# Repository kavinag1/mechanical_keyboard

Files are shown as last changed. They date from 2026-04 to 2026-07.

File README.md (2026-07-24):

# Building My Own 60% Mechanical Keyboard with a Raspberry Pi Pico

I have been wanting a mechanical keyboard. So instead of buying one why not make one. This was not really a easy journey but I am proud of what all I have learnt

---

## The Journey

### Step 0: Deciding the keyboard (1hr)
Over the past few days, I researched different types of keyboards to decide what I want to build. I compared layouts like 40%, 60%, 65%, and TKL, and chose a 60% layout because it offers a good balance between size and functionality while still being manageable to design. I also looked at existing open-source designs like the CO60 to understand how keyboard PCBs are structured and to confirm standard design practices.

I also researched switches, connectivity, and firmware. I selected EPOMAKER Creamy Jade switches because they are MX-style and compatible with standard footprints. I decided to make the keyboard wired instead of wireless to reduce complexity and allow me to use QMK firmware more easily.

The final specifications of my keyboard include a 60% layout, MX-style 5-pin switches, a row-column matrix with 1N4148 diodes, USB-C connectivity, and an STM32-based microcontroller. I will also include a rotary encoder for extra functionality and simple per-key backlighting. This research helped me clearly define my design before moving on to the PCB stage.

### Step 1: Learning What a Keyboard Matrix Is (1.5hr)

so before I could build this keyboard I needed to pratice what keyboard matrix is and understand how it works. So I followed a tutorial to make a simple and easy 3 by 3 keybaord matrix like the one you can see in the image. Keyboard matrix allows you to add more keys and use less number of pins like here I used 9 keys but only used 6 pins. This would be useful in the future when making the actual keyboard cause raspberry pico has only so many number of pins.

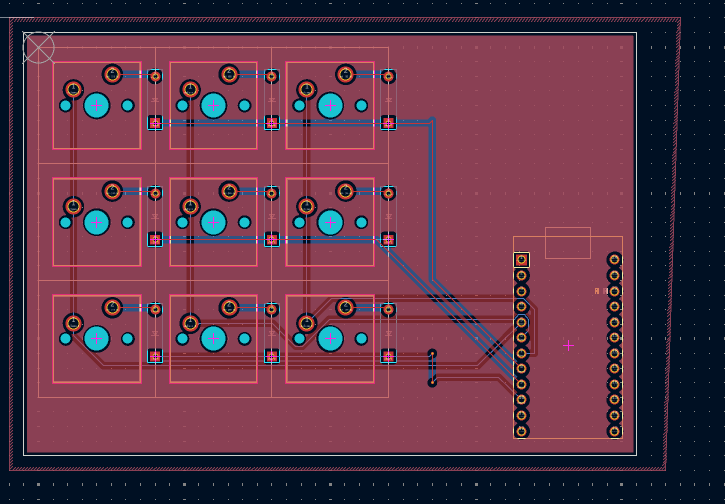
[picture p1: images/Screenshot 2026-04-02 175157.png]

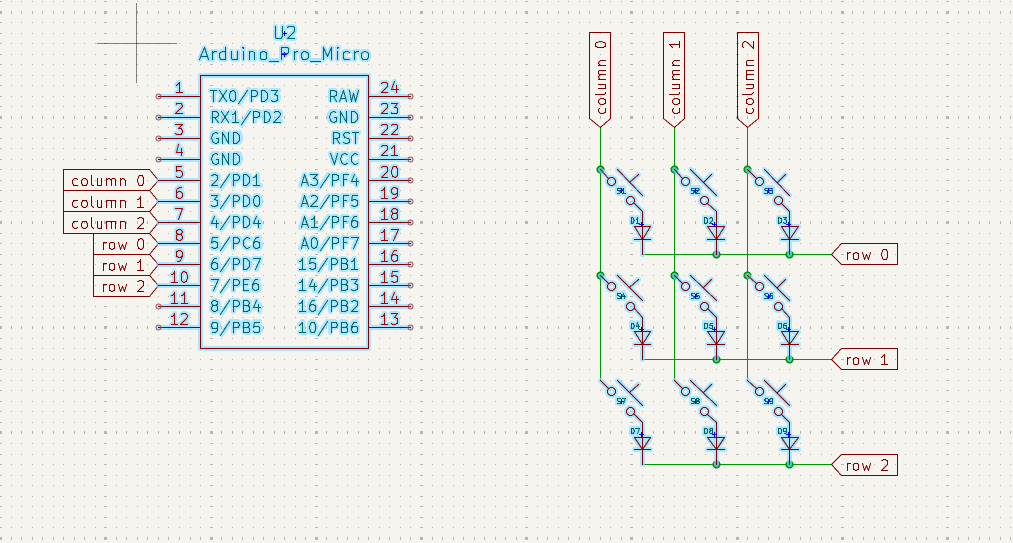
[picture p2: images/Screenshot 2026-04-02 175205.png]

Once I understood the concept, I mapped out the full 60-key layout I wanted to build — a standard 60% ANSI arrangement: 5 rows and 14 columns.
this is the layout of the keyboard I went with

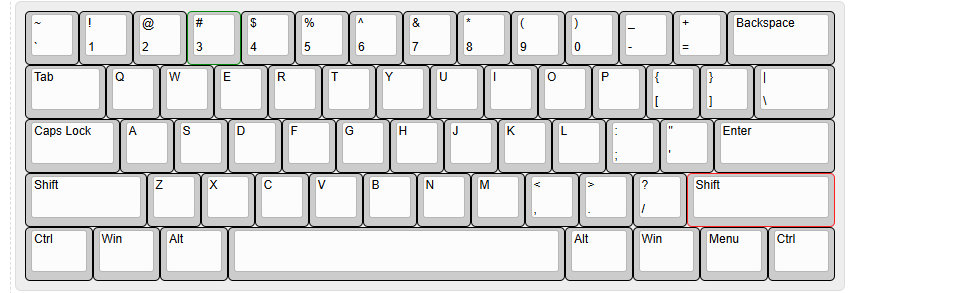
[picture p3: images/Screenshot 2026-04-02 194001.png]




---

### Step 2: Designing the Schematic (2hr)

now after finalising the layout of my keyboard I needed to make the schematic of the keyboard. each key would need a switch and then a diode connected to it to prevnt phantom keypresses as if the diode are not present, when you are pressing multiple keys some keys you didnt press will also register and we dont want that. So I arranged the keys in a form of a matrix then conected the rows and collom pins to my GPIO pin in the pico. and then I also added a oled screen and a knob for the keyabord cause why not.

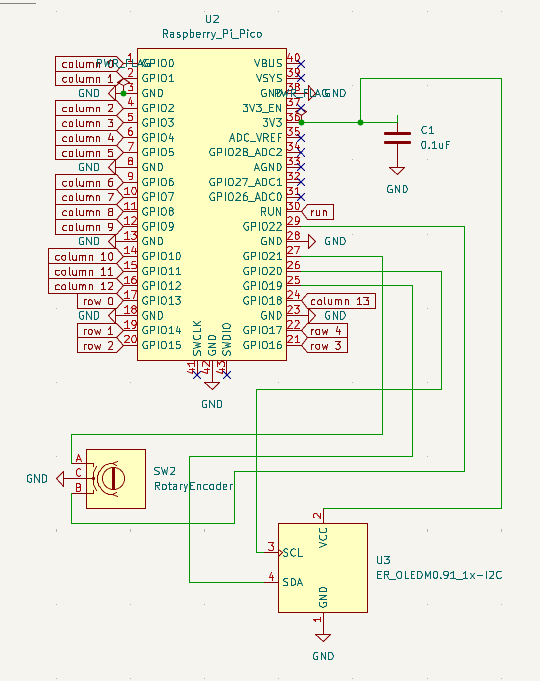
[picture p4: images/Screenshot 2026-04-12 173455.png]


---

### Step 3: Routing the PCB (1hr)

With the schematic done, I moved on to laying out and routing the actual PCB. 
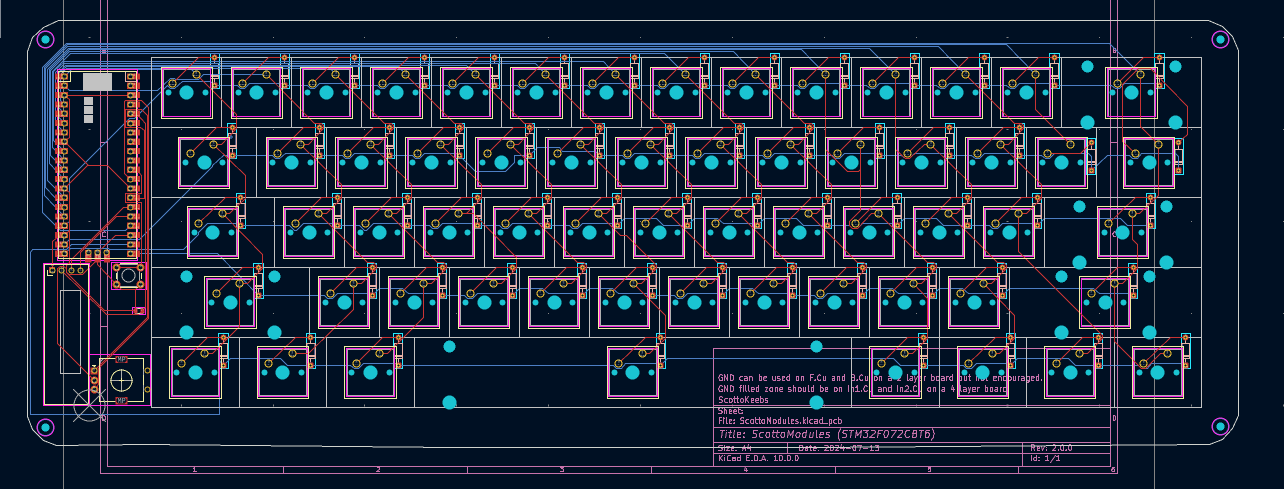
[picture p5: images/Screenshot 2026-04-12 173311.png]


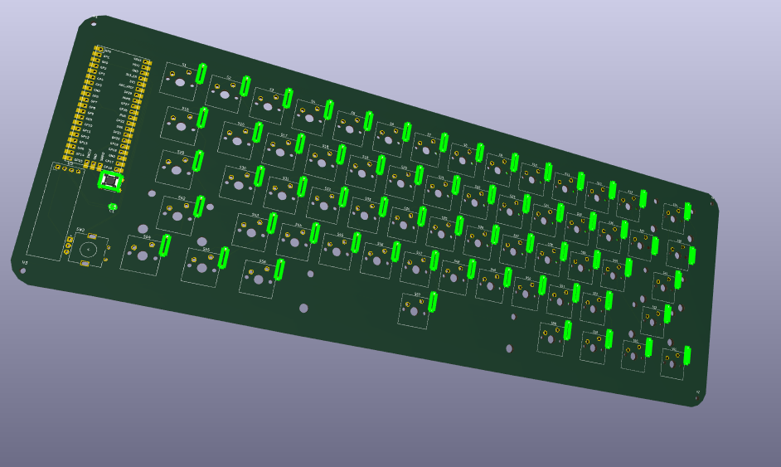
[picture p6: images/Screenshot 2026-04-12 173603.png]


the peices I used are given in the BOM if you want to use the same parts

---

### Step 4:Writing the firmware (1.3hr)

The firmware was developed to act as the core software controlling the mechanical keyboard. I configured the keyboard's key matrix so that every physical switch was correctly mapped to its corresponding keycode and created a custom keymap defining the functionality of each key. 

### Step 5: adding the screen and the knob (3hr)

later on I wanted to add the knob and scren as well. for which I had to change the entire PCB again as I need to create more space for both of them. It took me some time to get the pcb right again. So I had to reroute all the wires makwe the scehmatic again and finally I was able to make it. I also had to make changes to the firmware code.

### Step 6: Designing the Case (2hr + 2hr)

I designed the case two times first was without the screen and the knob and was very basic because I spent time figuuring out how to add the spaces for the keyboard in the first design and then later I changed it to a more ergonomic design.

Then the final step was designing the case itself. For this I would reccomened exporting the PCB as a stl file and adding it in your cad to see if it fits your case or not. It saved me multiple times as I messed up the dimensions but this is the final case I eneded up with which perectly fits the PCB inside. for the case as you can see I went with a open desgin wherethe top part is open so that i can somewhat see the PCB just to remind me this is something I have created on my own.

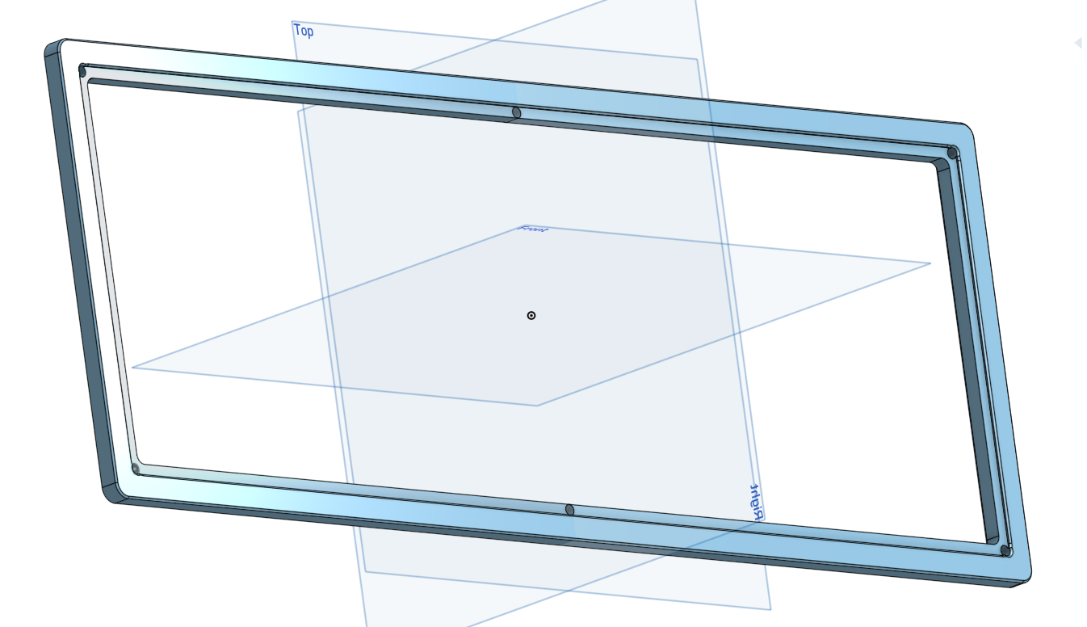
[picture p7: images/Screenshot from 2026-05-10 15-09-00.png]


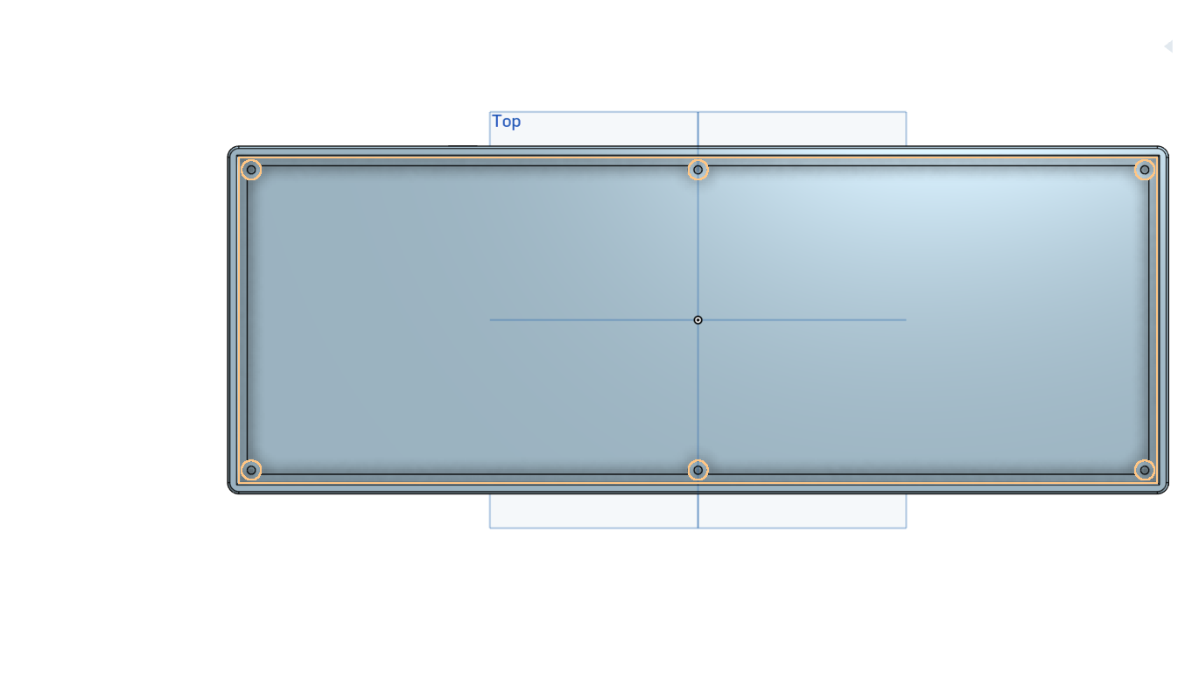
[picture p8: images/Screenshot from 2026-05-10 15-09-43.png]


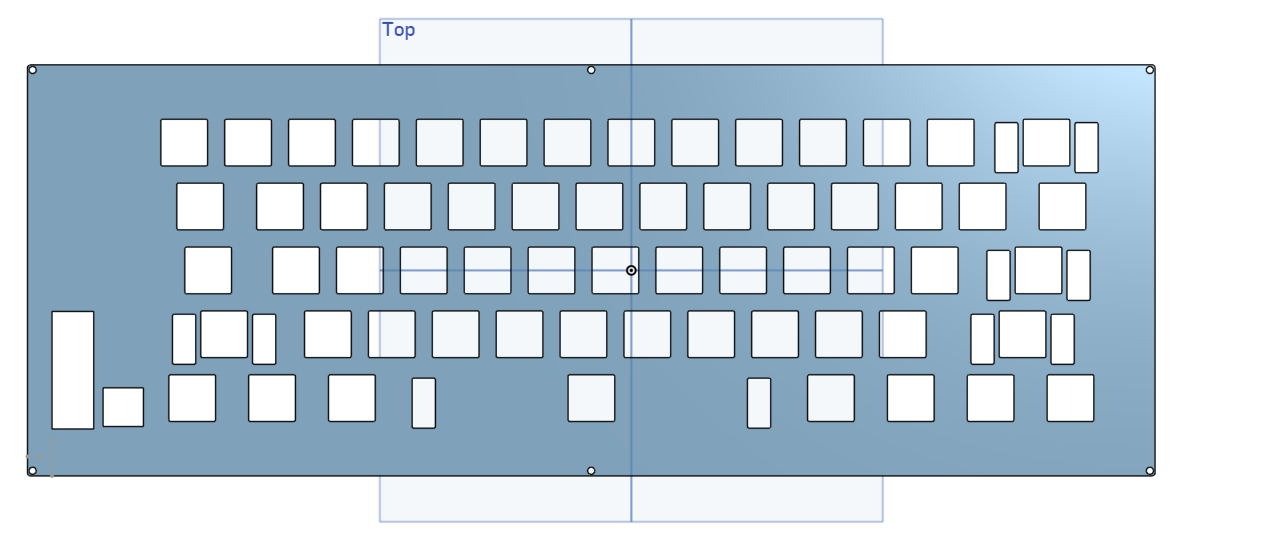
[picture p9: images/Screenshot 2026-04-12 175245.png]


### Step 7: making the case cooler (2hr)

after desiging the case I though of adding something on the back. For that I decided an engraving of the character brook from one peice./ So for that first i found and took inpiration from an arrt to create one fro the aspoect ratio of my keyboard. After which I uploaded the art on inkscape where i made the bitmap of the art. then i saved it as a dxf file which then I imported on onshape. AFter importing I resized itg and placed it on my case. I tried to extrude the whole sketch as it is but that didnt work because some part of the sketch broke. So I slowly divided it into difffernt parts and did it one by one. Overall I am pretty happy with the design.

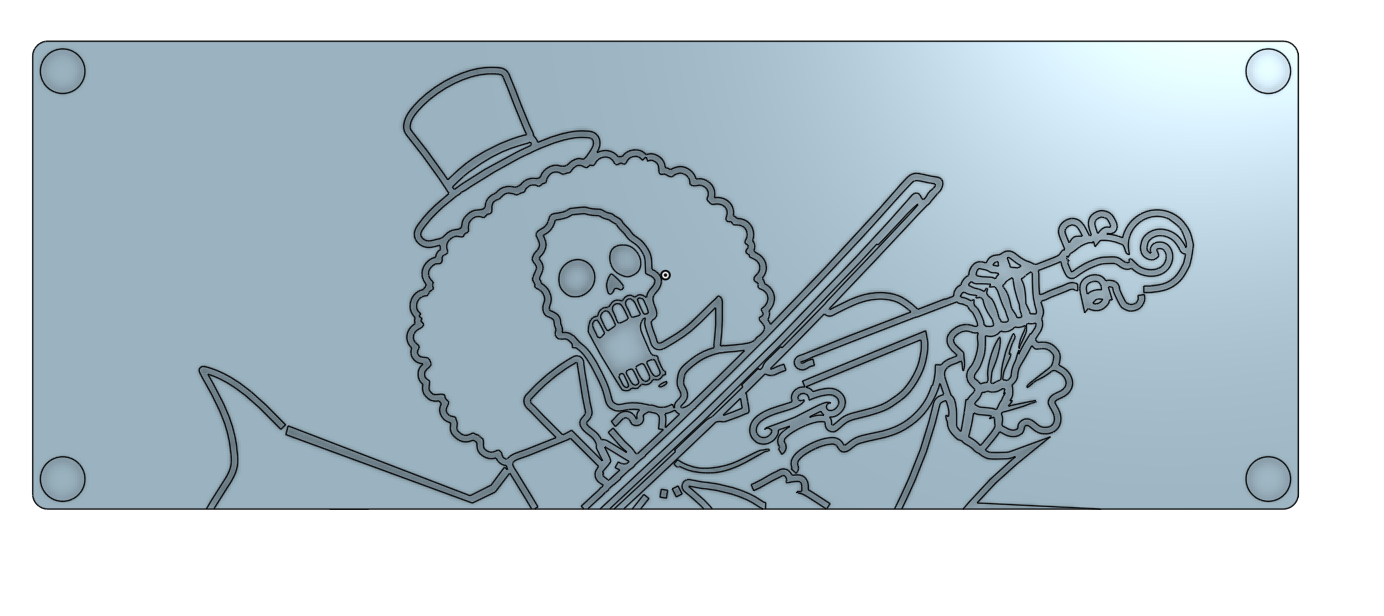
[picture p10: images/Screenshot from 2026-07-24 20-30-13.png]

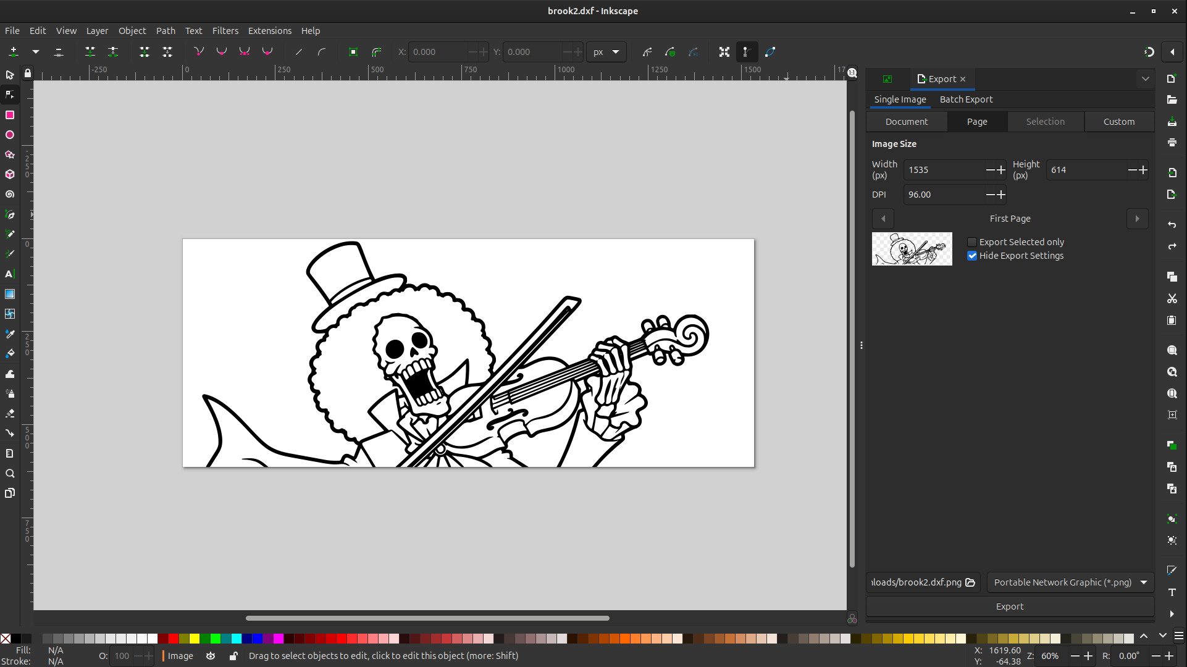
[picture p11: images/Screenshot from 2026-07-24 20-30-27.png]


## Bill of Materials

| Component | Purpose | Qty | Cost (USD) | Distributor | Link |
|---|---|-----|---|---|---|
| Screen | The screen for the keyboard | 1 | $1.56 | Tech Delivers | [Buy](https://techdelivers.com/0-91-inch-oled-lcd-display-module-blue-128x32-i2c-iic-serial?tag=i2c%20lcd) |
| Micro USB Cable | To connect the Pico | 1 | $0.41 | robo craze | [Buy](https://robocraze.com/products/usb-to-micro-usb-cable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) |
| M2 Heat Set Inserts | For case assembly | 1 pack | $0.46 | Robu | [Buy]([https://www.amazon.in/BRASS-WAREHOUSE-Knurled-Threaded-Printing/dp/B0FMPZ3QHL/](https://robu.in/product/m2-x-4-mm-brass-insert/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)) |
| M2 Screws (20 pack) | Screwing the case | 1 pack | $1.5 | Robu | [Buy]([https://www.amazon.in/Tia-Golden-Screws-Length-Approx-480pcs/dp/B07VWKBHYZ/](https://robu.in/product/easymech-ss-304-csk-countersunk-philips-head-m2-x-8-mm-bolt-25-pcs/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) |
| Keycaps | Keycaps for the keyboard | 1 set | $13.5 | curisosity caps | [Buy]([https://meckeys.com/shop/accessories/keyboard-accessories/keycaps/grey-black-keycaps/](https://curiositycaps.in/products/cloud-lake-cherry-doubleshot-pbt-keycaps?_pos=14&_fid=805e1adb4&_ss=c)) |
| Gateron Switches | Switches for the keys | 7 packs | $13.37 | stackskb | [Buy]([https://meckeys.com/shop/accessories/keyboard-accessories/key-switches/gateron-optical-switch-pack/](https://stackskb.com/store/click-inc-of-linear-switch-pack-of-10/)) |
| Raspberry Pi Pico | The brain | 1 | $4.00 | Robu.in | [Buy](https://robu.in/product/raspberry-pi-pico/) |
| 3D Printed Case | The case | 1 | $16.18 | Robo In | — |
| DIODE | Its the diode for the circuit | 100 | $1.02 | Robu | [Buy]([https://www.amazon.in/Circuit-Ranger-Switching-Electronic-Projects/dp/B0FJLP12GX](https://robu.in/product/1n4148-1w-zener-diode-pack-of-50/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)) |
| PCB | It is the pcb of the keyboard | 5 | $64 | JLCPCB | — |
| **Total** | | | **$116** | | |

---

rols.

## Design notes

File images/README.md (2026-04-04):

# Images for Your Keyboard Build

Add your build images here. The main README.md expects these files:

1. **pcb-layout.png** - Your PCB layout design (schematic showing 5x14 grid)
2. **pcb-routing.png** - The routed PCB traces/layers
3. **diode-diagram.png** - Close-up or diagram showing how diodes are connected
4. **case-design.png** - CAD model or rendering of your case design
5. **case-assembled.png** - Photo of the case assembled with PCB inside
6. **assembly-process.png** - Photos from building/soldering process
7. **finished-keyboard.png** - Final photo of the working keyboard

You can name them differently if you prefer - just update the image filenames in the main README.md to match.

Image formats: PNG, JPG, or GIF work best.

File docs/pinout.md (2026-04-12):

# GPIO Pinout Reference

## Row Pins (GPIO13-17)

| Row | GPIO | Pico Pin |
|-----|---|---|
| 0 | GP13 | 17 |
| 1 | GP14 | 19 |
| 2 | GP15 | 20 |
| 3 | GP16 | 21 |
| 4 | GP17 | 22 |

## Column Pins (GPIO0-12, 18)

| Col | GPIO | Pico Pin |
|-----|---|---|
| 0 | GP0  | 1 |
| 1 | GP1  | 2 |
| 2 | GP2  | 4 |
| 3 | GP3  | 5 |
| 4 | GP4  | 6 |
| 5 | GP5  | 7 |
| 6 | GP6  | 9 |
| 7 | GP7  | 10 |
| 8 | GP8  | 11 |
| 9 | GP9  | 12 |
| 10  | GP10 | 13 |
| 11  | GP11 | 14 |
| 12  | GP12 | 15 |
| 13  | GP18 | 24 |

## Wiring

Each switch connects: Row → [1N4148 Diode Anode] → Cathode Stripe → Column

The diode prevents ghosting when multiple keys are pressed.

## Layout

```
          COLUMNS
    ┌─────────────────────────────────────────────────────┐
    │ 0  1  2  3  4  5  6  7  8  9 10 11 12 13            │
┌───┼─────────────────────────────────────────────────────┤
│ 0 │ Esc 1  2  3  4  5  6  7  8  9  0  -  =  BSPC        │
├───┼─────────────────────────────────────────────────────┤
│ 1 │ TAB Q  W  E  R  T  Y  U  I  O  P  [  ]  \            │
├───┼─────────────────────────────────────────────────────┤
│ 2 │ CAPS A  S  D  F  G  H  J  K  L  ;  '     ENTER       │
├───┼─────────────────────────────────────────────────────┤
│ 3 │ SHIFT Z  X  C  V  B  N  M  ,  .  /      SHIFT       │
├───┼─────────────────────────────────────────────────────┤
│ 4 │ CTRL WIN ALT      SPACE      ALT WIN MNU CTRL       │
└───┴─────────────────────────────────────────────────────┘
```

## OLED Display Pins (SSD1306 128×32, I2C)

| Signal | GPIO | Pico Pin |
|---|---|---|
| SCL | GP26 | 31 |
| SDA | GP25 | 34 |

Uses I2C1 peripheral (`I2C1_DRIVER`).

## Rotary Encoder Pins

| Signal | GPIO | Pico Pin |
|---|---|---|
| A | GP27 | 32 |
| B | GP29 | 35 |

The encoder controls volume on layer 0 (rotate = vol down/up) and track navigation on layer 1 (rotate = prev/next track).

## Configuration

```c
#define MATRIX_ROW_PINS { GP13, GP14, GP15, GP16, GP17 }
#define MATRIX_COL_PINS { GP0, GP1, GP2, GP3, GP4, GP5, GP6, GP7, GP8, GP9, GP10, GP11, GP12, GP18 }

// OLED (I2C1)
#define I2C_DRIVER I2C1_DRIVER
#define I2C1_SCL_PIN GP26
#define I2C1_SDA_PIN GP25

// Rotary encoder
#define ENCODERS_PAD_A { GP27 }
#define ENCODERS_PAD_B { GP29 }
#define ENCODER_RESOLUTION 4
```

## Testing Individual Keys via REPL

You can test your keyboard via the QMK REPL (if available on your Pico):

```python
# Test if a switch is working
# Press the key at Row 0, Column 0 (ESC key)
# The REPL should show the matrix position being read
```

For more detailed debugging, compile with `DEBUG_MATRIX_SCAN_RATE` enabled in `rules.mk`.

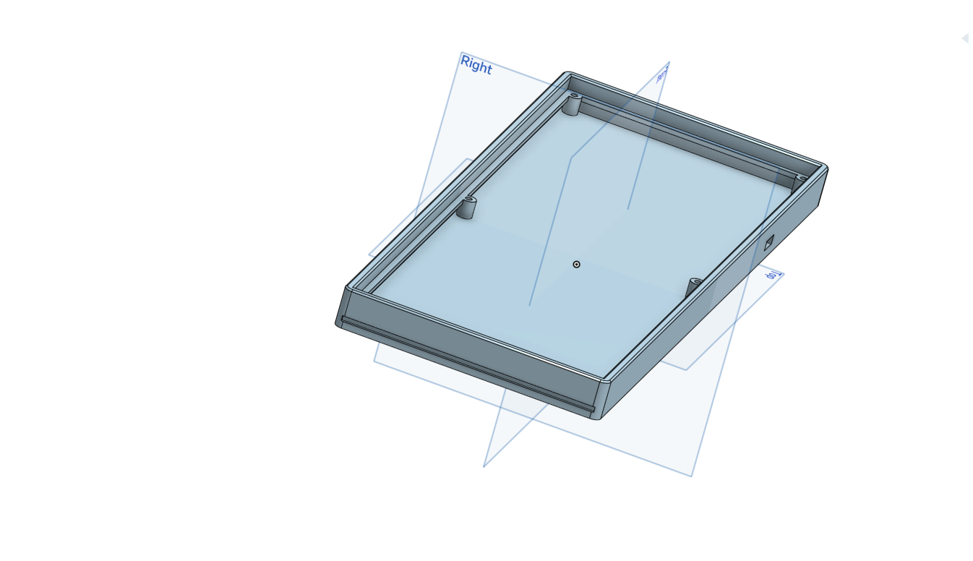
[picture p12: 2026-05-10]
images/Screenshot from 2026-05-10 15-10-26.png

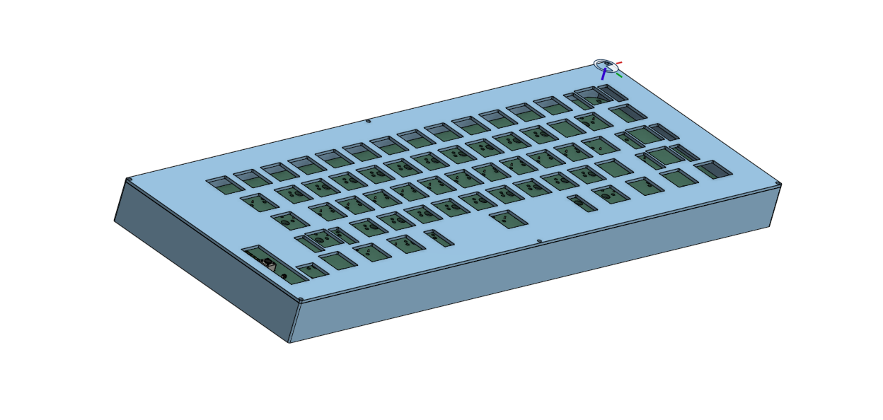
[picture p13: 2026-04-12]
images/Screenshot 2026-04-12 175235.png

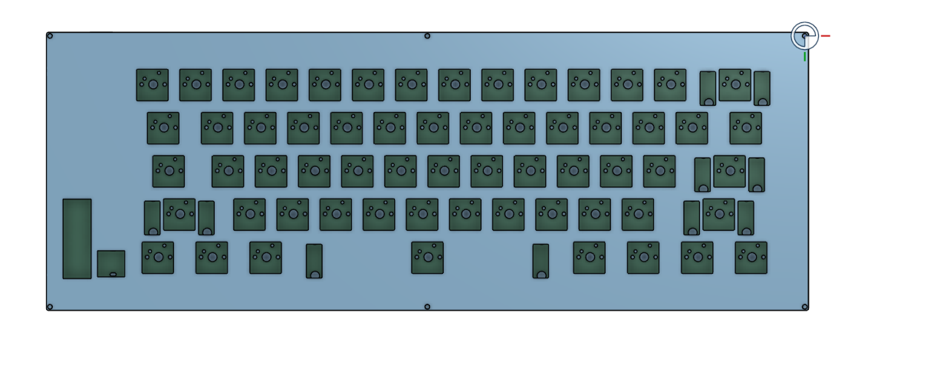
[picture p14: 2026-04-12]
images/Screenshot 2026-04-12 175226.png

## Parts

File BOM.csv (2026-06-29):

Component | Purpose | Qty | Cost (USD) | Distributor | Link
Screen | The screen for the keyboard | 1 | $1.56 | Tech Delivers | https://techdelivers.com/0-91-inch-oled-lcd-display-module-blue-128x32-i2c-iic-serial?tag=i2c%20lcd
Micro USB Cable | To connect the Pico | 1 | $1.62 | Amazon | https://www.amazon.in/Ambrane-Unbreakable-Charging-Braided-Android/dp/B082LZGK39/
M2 Heat Set Inserts | For case assembly | 1 pack | $3.31 | Amazon | https://www.amazon.in/BRASS-WAREHOUSE-Knurled-Threaded-Printing/dp/B0FMPZ3QHL/
M2 Screws (20 pack) | Screwing the case | 1 pack | $1.93 | Amazon | https://www.amazon.in/Tia-Golden-Screws-Length-Approx-480pcs/dp/B07VWKBHYZ/
Keycaps | Keycaps for the keyboard | 1 set | $10.76 | Meckeys | https://meckeys.com/shop/accessories/keyboard-accessories/keycaps/grey-black-keycaps/
Gateron Switches | Switches for the keys | 7 packs | $15.12 | Meckeys | https://meckeys.com/shop/accessories/keyboard-accessories/key-switches/gateron-optical-switch-pack/
Raspberry Pi Pico | The brain | 1 | $4.00 | Robu.in | https://robu.in/product/raspberry-pi-pico/
3D Printed Case | The case | 1 | $16.18 | Robo In
DIODE | Its the diode for the circuit | 1 | $3.08 | Amazon | https://www.amazon.in/Circuit-Ranger-Switching-Electronic-Projects/dp/B0FJLP12GX
PCB | It is the pcb of the keyboard | 5 | $36.01 | JLCPCB
Total |  |  |  | $93.57

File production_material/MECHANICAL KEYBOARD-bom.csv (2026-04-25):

Name | Purpose | Quantity | Total Cost (USD) | Link | Distributor
screen | the screen for the keybaord | 1 | 1.56 | https://techdelivers.com/0-91-inch-oled-lcd-display-module-blue-128x32-i2c-iic-serial?tag=i2c%20lcd | tech delivers
micro usb | to connect the pico | 1 | 0.41 | https://www.amazon.in/Ambrane-Unbreakable-Charging-Braided-Android/dp/B082LZGK39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 | Robo craze
M2 Heat Set Inserts | for helping with screwing | 1 | 0.46 | https://www.amazon.in/BRASS-WAREHOUSE-Knurled-Threaded-Printing/dp/B0FMPZ3QHL | Robu
M2 screws 20 pack | screwing the case | 1 | 1.50 | https://www.amazon.in/Tia-Golden-Screws-Length-Approx-480pcs/dp/B07VWKBHYZ | Robu
keycaps | the keycaps for the keyboard | 1 | 13.79 | https://meckeys.com/shop/accessories/keyboard-accessories/keycaps/grey-black-keycaps/ | Curiosity caps
Gateron Switches | switches for the keys | 7 | 13.37 | https://meckeys.com/shop/accessories/keyboard-accessories/key-switches/gateron-optical-switch-pack/ | Stackskb
Raspberry Pi Pico | the brain | 1 | 4.00 | https://robu.in/product/raspberry-pi-pico/ | robu
3d printed case | the case | 1 | 16.18 |  | robo in
DIODE | its the diode for the circuit | 100 | 1.02 | https://www.amazon.in/Circuit-Ranger-Switching-Electronic-Projects/dp/B0FJLP12GX | Robu
PCB | it is the pcb of the keyboard | 5 | 36.01 |  | JLCPCB

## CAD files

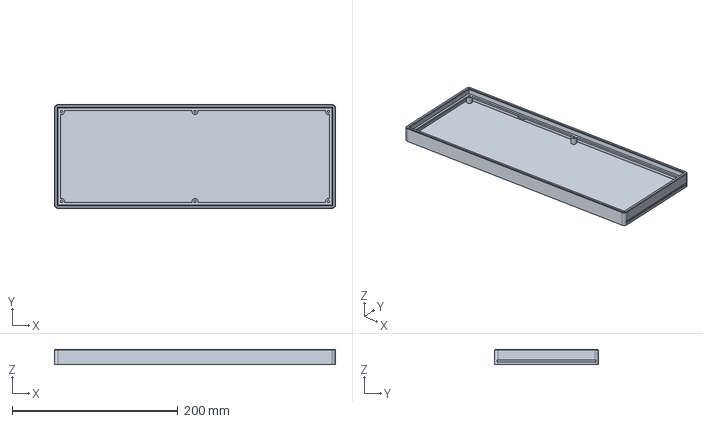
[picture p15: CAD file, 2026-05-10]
cad/bottom_case_v2.step
338.9 x 125.2 x 18.5 mm

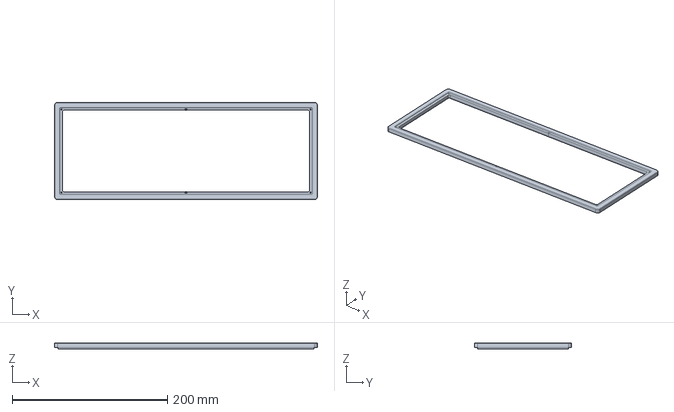
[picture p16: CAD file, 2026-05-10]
cad/top_case_v2.step
338.9 x 125.2 x 7.50 mm

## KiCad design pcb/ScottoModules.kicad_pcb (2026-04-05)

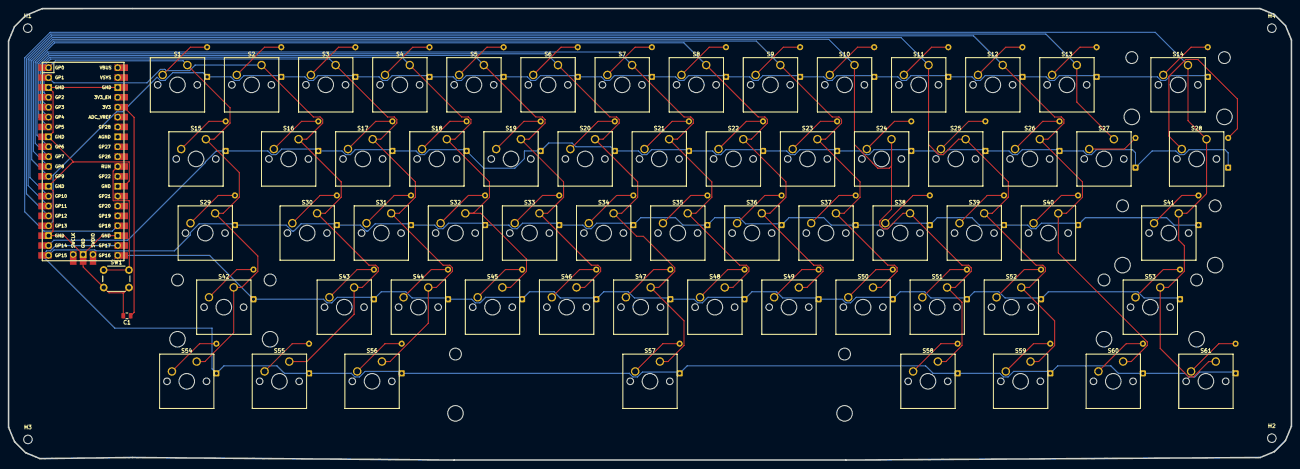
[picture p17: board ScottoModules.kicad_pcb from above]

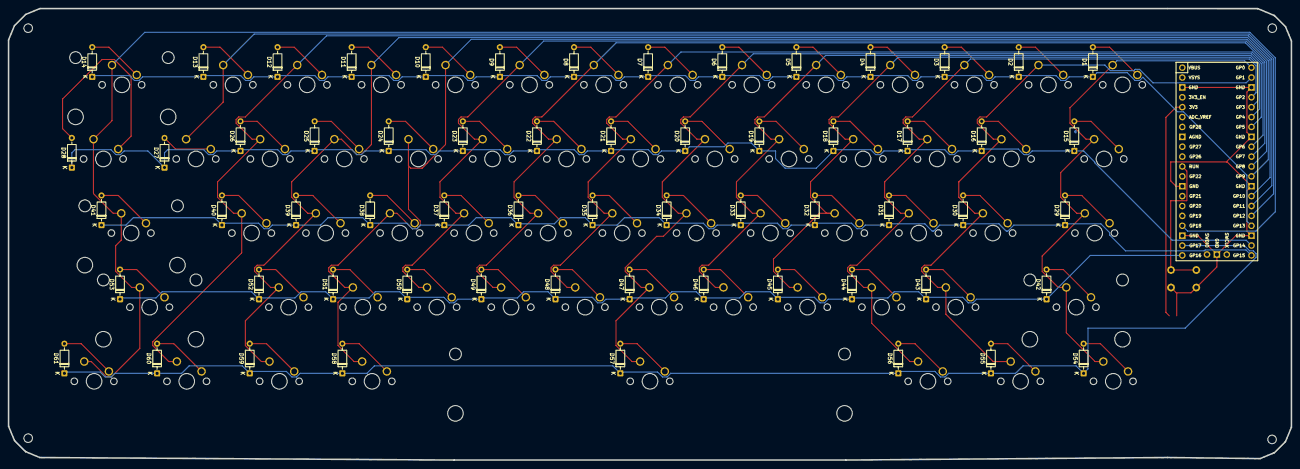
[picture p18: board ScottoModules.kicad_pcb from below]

Board: 4 copper layers, 329.7 x 116.0 mm, 129 parts (61 on the bottom side), 83 nets.

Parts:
C1: 0.1uF; C_0805_2012Metric
D1, D2, D3, D4, D5, D6, D7, D8, D9, D10, D11, D12, D13, D14, D15, D16, D17, D18, D19, D20, D21, D22, D23, D24, D25, D26, D27, D28, D29, D30, D31, D32, D33, D34, D35, D36, D37, D38, D39, D40, D41, D42, D43, D44, D45, D46, D47, D48, D49, D50, D51, D52, D53, D54, D55, D56, D57, D58, D59, D60, D61: D_DO-35_SOD27_P7.62mm_Horizontal
H1, H2, H3, H4: MountingHole; MountingHole_2.2mm_M2
S1, S2, S3, S4, S5, S6, S7, S8, S9, S10, S11, S12, S13, S16, S17, S18, S19, S20, S21, S22, S23, S24, S25, S26, S27, S30, S31, S32, S33, S34, S35, S36, S37, S38, S39, S40, S43, S44, S45, S46, S47, S48, S49, S50, S51, S52: SW_Cherry_MX_1.00u_PCB
S14: SW_Cherry_MX_2.00u_PCB
S15, S28: SW_Cherry_MX_1.50u_PCB
S29: SW_Cherry_MX_1.75u_PCB
S41, S42: SW_Cherry_MX_2.25u_PCB
S53: SW_Cherry_MX_2.75u_PCB
S54, S55, S56, S58, S59, S60, S61: SW_Cherry_MX_1.25u_PCB
S57: SW_Cherry_MX_6.25u_PCB
SW1: SW_Push; SW_PUSH_6mm
U2: Raspberry_Pi_Pico

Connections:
GND: C1.2, SW1.2, U2.3 (GND), U2.8 (GND), U2.13 (GND), U2.18 (GND), U2.23 (GND), U2.28 (GND), U2.38 (GND), U2.42 (GND)
unnamed: D1.2 (A), S1.2
unnamed: D2.2 (A), S2.2
unnamed: D3.2 (A), S3.2
unnamed: D4.2 (A), S4.2
unnamed: D5.2 (A), S5.2
unnamed: D6.2 (A), S6.2
unnamed: D7.2 (A), S7.2
unnamed: D8.2 (A), S8.2
unnamed: D9.2 (A), S9.2
unnamed: D10.2 (A), S10.2
unnamed: D11.2 (A), S11.2
unnamed: D12.2 (A), S12.2
unnamed: D13.2 (A), S13.2
unnamed: D14.2 (A), S14.2
unnamed: D15.2 (A), S15.2
unnamed: D16.2 (A), S16.2
unnamed: D17.2 (A), S17.2
unnamed: D18.2 (A), S18.2
unnamed: D19.2 (A), S19.2
unnamed: D20.2 (A), S20.2
unnamed: D21.2 (A), S21.2
unnamed: D22.2 (A), S22.2
unnamed: D23.2 (A), S23.2
unnamed: D24.2 (A), S24.2
unnamed: D25.2 (A), S25.2
unnamed: D26.2 (A), S26.2
unnamed: D27.2 (A), S27.2
unnamed: D28.2 (A), S28.2
unnamed: D29.2 (A), S29.2
unnamed: D30.2 (A), S30.2
unnamed: D31.2 (A), S31.2
unnamed: D32.2 (A), S32.2
unnamed: D33.2 (A), S33.2
unnamed: D34.2 (A), S34.2
unnamed: D35.2 (A), S35.2
unnamed: D36.2 (A), S36.2
unnamed: D37.2 (A), S37.2
unnamed: D38.2 (A), S38.2
unnamed: D39.2 (A), S39.2
unnamed: D40.2 (A), S40.2
unnamed: D41.2 (A), S41.2
unnamed: D42.2 (A), S42.2
unnamed: D43.2 (A), S43.2
unnamed: D44.2 (A), S44.2
unnamed: D45.2 (A), S45.2
unnamed: D46.2 (A), S46.2
unnamed: D47.2 (A), S47.2
unnamed: D48.2 (A), S48.2
unnamed: D49.2 (A), S49.2
unnamed: D50.2 (A), S50.2
unnamed: D51.2 (A), S51.2
unnamed: D52.2 (A), S52.2
unnamed: D53.2 (A), S53.2
unnamed: D54.2 (A), S54.2
unnamed: D55.2 (A), S55.2
unnamed: D56.2 (A), S56.2
unnamed: D57.2 (A), S57.2
unnamed: D58.2 (A), S58.2
unnamed: D59.2 (A), S59.2
unnamed: D60.2 (A), S60.2
unnamed: D61.2 (A), S61.2
unnamed: C1.1, U2.36 (3V3)
column 0: S1.1, S15.1, S29.1, S42.1, S54.1, U2.1 (GPIO0)
column 1: S2.1, S16.1, S30.1, S43.1, S55.1, U2.2 (GPIO1)
column 2: S3.1, S17.1, S31.1, S44.1, S56.1, U2.4 (GPIO2)
column 3: S4.1, S18.1, S32.1, S45.1, U2.5 (GPIO3)
column 4: S5.1, S19.1, S33.1, S46.1, U2.6 (GPIO4)
column 5: S6.1, S20.1, S34.1, S47.1, S57.1, U2.7 (GPIO5)
column 6: S7.1, S21.1, S35.1, S48.1, U2.9 (GPIO6)
column 7: S8.1, S22.1, S36.1, S49.1, U2.10 (GPIO7)
column 8: S9.1, S23.1, S37.1, S50.1, U2.11 (GPIO8)
column 9: S10.1, S24.1, S38.1, S51.1, S58.1, U2.12 (GPIO9)
column 10: S11.1, S25.1, S39.1, S52.1, S59.1, U2.14 (GPIO10)
column 11: S12.1, S26.1, S40.1, S60.1, U2.15 (GPIO11)
column 12: S13.1, S27.1, U2.16 (GPIO12)
column 13: S14.1, S28.1, S41.1, S53.1, S61.1, U2.24 (GPIO18)
row 0: D1.1 (K), D2.1 (K), D3.1 (K), D4.1 (K), D5.1 (K), D6.1 (K), D7.1 (K), D8.1 (K), D9.1 (K), D10.1 (K), D11.1 (K), D12.1 (K), D13.1 (K), D14.1 (K), U2.17 (GPIO13)
row 1: D15.1 (K), D16.1 (K), D17.1 (K), D18.1 (K), D19.1 (K), D20.1 (K), D21.1 (K), D22.1 (K), D23.1 (K), D24.1 (K), D25.1 (K), D26.1 (K), D27.1 (K), D28.1 (K), U2.19 (GPIO14)
row 2: D29.1 (K), D30.1 (K), D31.1 (K), D32.1 (K), D33.1 (K), D34.1 (K), D35.1 (K), D36.1 (K), D37.1 (K), D38.1 (K), D39.1 (K), D40.1 (K), D41.1 (K), U2.20 (GPIO15)
row 3: D42.1 (K), D43.1 (K), D44.1 (K), D45.1 (K), D46.1 (K), D47.1 (K), D48.1 (K), D49.1 (K), D50.1 (K), D51.1 (K), D52.1 (K), D53.1 (K), U2.21 (GPIO16)
row 4: D54.1 (K), D55.1 (K), D56.1 (K), D57.1 (K), D58.1 (K), D59.1 (K), D60.1 (K), D61.1 (K), U2.22 (GPIO17)
run: SW1.1, U2.30 (RUN)

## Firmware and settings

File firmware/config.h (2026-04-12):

#pragma once

#include "config_common.h"

#define VENDOR_ID       0xCAFE
#define PRODUCT_ID      0xDEAD
#define DEVICE_VER      0x0001
#define MANUFACTURER    "Kavin"
#define PRODUCT         "60% Keyboard"

#define MATRIX_ROWS     5
#define MATRIX_COLS     14

#define MATRIX_ROW_PINS { GP13, GP14, GP15, GP16, GP17 }
#define MATRIX_COL_PINS { GP0, GP1, GP2, GP3, GP4, GP5, GP6, GP7, GP8, GP9, GP10, GP11, GP12, GP18 }

#define DIODE_DIRECTION COL2ROW
#define DEBOUNCE 20

#define LOCKING_SUPPORT_ENABLE
#define LOCKING_RESYNC_ENABLE
#define PREVENT_STUCK_MODIFIERS

#define USB_POLLING_INTERVAL_MS 1
#define FORCE_NKRO

// OLED display (SSD1306 128x32 via I2C)
// SCL = GP26, SDA = GP25
#define I2C_DRIVER I2CD2
#define I2C1_SCL_PIN GP26
#define I2C1_SDA_PIN GP25
#define OLED_DISPLAY_128X32
#define OLED_TIMEOUT 30000

// Rotary encoder
// A = GP27, B = GP29
#define ENCODERS_PAD_A { GP27 }
#define ENCODERS_PAD_B { GP29 }
#define ENCODER_RESOLUTION 4

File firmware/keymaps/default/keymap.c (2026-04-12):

#include QMK_KEYBOARD_H

const uint16_t PROGMEM keymaps[][MATRIX_ROWS][MATRIX_COLS] = {
    // Layer 0: QWERTY
    [0] = {
        {KC_ESC,  KC_1,    KC_2,    KC_3,    KC_4,    KC_5,    KC_6,    KC_7,    KC_8,    KC_9,    KC_0,    KC_MINS, KC_EQL,  KC_BSPC},
        {KC_TAB,  KC_Q,    KC_W,    KC_E,    KC_R,    KC_T,    KC_Y,    KC_U,    KC_I,    KC_O,    KC_P,    KC_LBRC, KC_RBRC, KC_BSLS},
        {KC_CAPS, KC_A,    KC_S,    KC_D,    KC_F,    KC_G,    KC_H,    KC_J,    KC_K,    KC_L,    KC_SCLN, KC_QUOT, KC_NO,   KC_ENT},
        {KC_LSFT, KC_Z,    KC_X,    KC_C,    KC_V,    KC_B,    KC_N,    KC_M,    KC_COMM, KC_DOT,  KC_SLSH, KC_NO,   KC_NO,   KC_RSFT},
        {KC_LCTL, KC_LGUI, KC_LALT, KC_NO,   KC_NO,   KC_SPC,  KC_NO,   KC_NO,   KC_RALT, KC_RGUI, KC_NO,   KC_NO,   KC_NO,   KC_RCTL},
    },

    // Layer 1: Function/Media
    [1] = {
        {KC_GRV,  KC_F1,   KC_F2,   KC_F3,   KC_F4,   KC_F5,   KC_F6,   KC_F7,   KC_F8,   KC_F9,   KC_F10,  KC_F11,  KC_F12,  KC_DEL},
        {_______, KC_HOME, KC_UP,   KC_END,  KC_PGUP, _______, _______, _______, _______, KC_PSCR, KC_SLCK, KC_PAUS, _______, _______},
        {_______, KC_LEFT, KC_DOWN, KC_RGHT, KC_PGDN, _______, KC_LEFT, KC_DOWN, KC_UP,   KC_RGHT, _______, _______, _______, _______},
        {_______, KC_VOLD, KC_VOLU, KC_MUTE, _______, _______, _______, _______, _______, _______, _______, _______, _______, _______},
        {_______, _______, _______, _______, _______, _______, _______, _______, _______, _______, _______, _______, _______, _______},
    },
};

// Encoder map: rotate to change volume, press to mute
#if defined(ENCODER_MAP_ENABLE)
const uint16_t PROGMEM encoder_map[][NUM_ENCODERS][NUM_DIRECTIONS] = {
    [0] = { ENCODER_CCW_CW(KC_VOLD, KC_VOLU) },
    [1] = { ENCODER_CCW_CW(KC_MPRV, KC_MNXT) },
};
#endif

// OLED display
#ifdef OLED_ENABLE
static void render_status(void) {
    // Keyboard name
    oled_write_P(PSTR("60% KB | "), false);

    // Current layer
    oled_write_P(PSTR("Layer: "), false);
    switch (get_highest_layer(layer_state)) {
        case 0:
            oled_write_P(PSTR("QWERTY  "), false);
            break;
        case 1:
            oled_write_P(PSTR("FN/MEDIA"), false);
            break;
        default:
            oled_write_P(PSTR("UNKNOWN "), false);
            break;
    }

    oled_write_P(PSTR("\n"), false);

    // Modifier indicators
    uint8_t mods = get_mods() | get_oneshot_mods();
    oled_write_P(mods & MOD_MASK_SHIFT ? PSTR("SFT ") : PSTR("    "), false);
    oled_write_P(mods & MOD_MASK_CTRL  ? PSTR("CTL ") : PSTR("    "), false);
    oled_write_P(mods & MOD_MASK_ALT   ? PSTR("ALT ") : PSTR("    "), false);
    oled_write_P(mods & MOD_MASK_GUI   ? PSTR("GUI ") : PSTR("    "), false);

    oled_write_P(PSTR("\n"), false);

    // Lock key indicators
    led_t leds = host_keyboard_led_state();
    oled_write_P(leds.caps_lock   ? PSTR("CAPS ") : PSTR("     "), false);
    oled_write_P(leds.num_lock    ? PSTR("NUM  ") : PSTR("     "), false);
    oled_write_P(leds.scroll_lock ? PSTR("SCR  ") : PSTR("     "), false);
}

bool oled_task_user(void) {
    render_status();
    return false;
}
#endif

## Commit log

2026-04-04 Initial commit: 60% mechanical keyboard firmware for Raspberry Pi Pico
2026-04-04 Convert to QMK firmware with actual PCB pinout configuration
    - Update GPIO pin assignments to match PCB layout (GP13-17 rows, GP0-12+GP18 columns)
    - Create QMK config.h with correct matrix size and pin definitions
    - Add keymaps/default/keymap.c with QWERTY layer and function layer
    - Create rules.mk and info.json for QMK build system
    - Add comprehensive QMK documentation for GPIO pinout and customization
    - Include INSTALL.md with QMK compilation and flashing instructions
    [config.h, keymap.c]
2026-04-04 Create comprehensive build guide README
    - Complete step-by-step assembly instructions
    - Detailed component list and cost breakdown
    - Hardware assembly phases (firmware, PCB, switches)
    - Comprehensive troubleshooting section
    - Customization guide with examples
    - References to design process and documentation
    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
2026-04-04 Fix: Remove duplicate DEBOUNCE definition in config.h
    [config.h]
2026-04-04 Further simplify README - only steps taken, remove all reference material
2026-04-04 Add ASCII diagrams, circuit explanation, and troubleshooting guide to README
2026-04-04 Add automated GitHub upload PowerShell script
2026-04-05 Add BOM table to README.md
    Agent-Logs-Url: https://github.com/kavinag1/mechanical_keyboard/sessions/757ec243-e3ee-478e-9da1-cacf7cee7caa
2026-04-05 Reorganize files into folders: cad/, pcb/, production_material/, firmware/
    - Rename 'Part Studio 2.step' to cad/bottom_case.step
    - Rename 'Part Studio 3.step' to cad/top_case.step
    - Move KiCad PCB files to pcb/
    - Move BOM and gerbers to production_material/
    - Move firmware files (config.h, rules.mk, info.json, keymaps/) to firmware/
    - Update README with new repository structure section
    [MECHANICAL KEYBOARD-bom.csv, ScottoModules.kicad_pcb, ScottoModules.kicad_sch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]
2026-04-05 Rewrite README: reorder steps, add 3x3 matrix intro, remove soldering/assembly/testing/file structure/troubleshooting sections
    Agent-Logs-Url: https://github.com/kavinag1/mechanical_keyboard/sessions/55de234f-2cd9-4d56-9ed2-190bfe4a9fce
2026-04-12 feat: add OLED display and rotary encoder support
    - config.h: add I2C1 pins for OLED (SCL=GP26, SDA=GP25) and encoder pins (A=GP27, B=GP29)
    - rules.mk: enable OLED_ENABLE, ENCODER_ENABLE, ENCODER_MAP_ENABLE
    - keymap.c: add oled_task_user() for layer/mod/lock display, add encoder_map for vol/media
    - docs/pinout.md: document OLED and encoder pins and configuration
    - README.md: add OLED and encoder to pin assignments and BOM
    Agent-Logs-Url: https://github.com/kavinag1/mechanical_keyboard/sessions/acb1897e-aee5-4937-a9d0-ccdec6fea8e2
2026-04-12 fix: use I2CD2 for I2C driver name and fix OLED spacing
    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
    [config.h, keymap.c]
2026-04-12 Update keyboard build images and BOM
    [MECHANICAL KEYBOARD-bom.csv]
2026-04-12 Update README, CAD model, and image set
    [top.step, top_case.step]
2026-04-24 Update BOM with new prices, quantities, and distributors
    Agent-Logs-Url: https://github.com/kavinag1/mechanical_keyboard/sessions/7156329a-06fe-4bd5-bbe3-e064ff1e64a8
    [MECHANICAL KEYBOARD-bom.csv]
2026-04-25 remove BOM items 3 and 4 (reset button and capacitor), update README total
    Agent-Logs-Url: https://github.com/kavinag1/mechanical_keyboard/sessions/9bd4889d-3662-482a-bfb3-7f0437decefc
    [MECHANICAL KEYBOARD-bom.csv]
2026-06-29 Add BOM.csv with bill of materials
    [BOM.csv]
